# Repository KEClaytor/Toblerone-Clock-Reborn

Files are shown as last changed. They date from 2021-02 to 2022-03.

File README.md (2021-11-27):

# Toblerone-Clock-Reborn
Mk 2 of the Toblerone Clock

Digits:

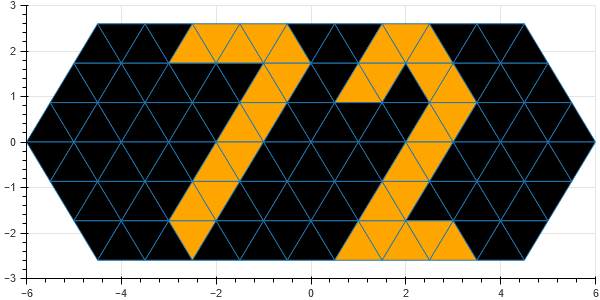
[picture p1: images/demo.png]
Numbers


Clock mode (hours are green, minutes orange, seconds blue):

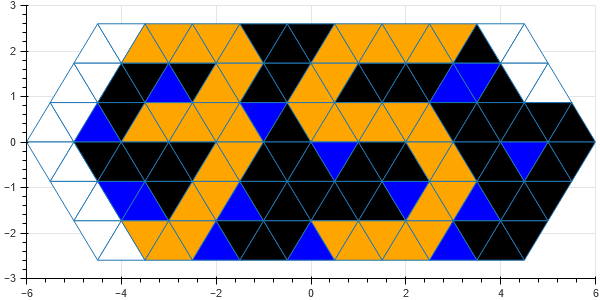
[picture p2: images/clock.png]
Clock mode


Pixel numbering scheme:

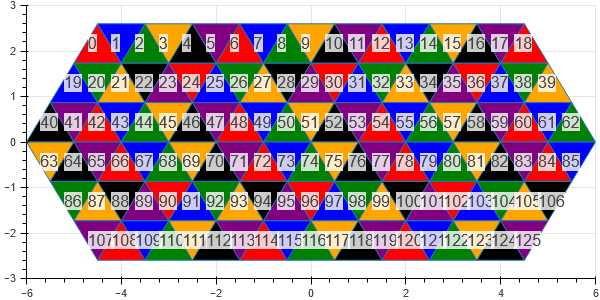
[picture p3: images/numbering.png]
Numbering


## Hardware

Wiring diagram (the pins tied together simulate how I created the nets on the protoboard).

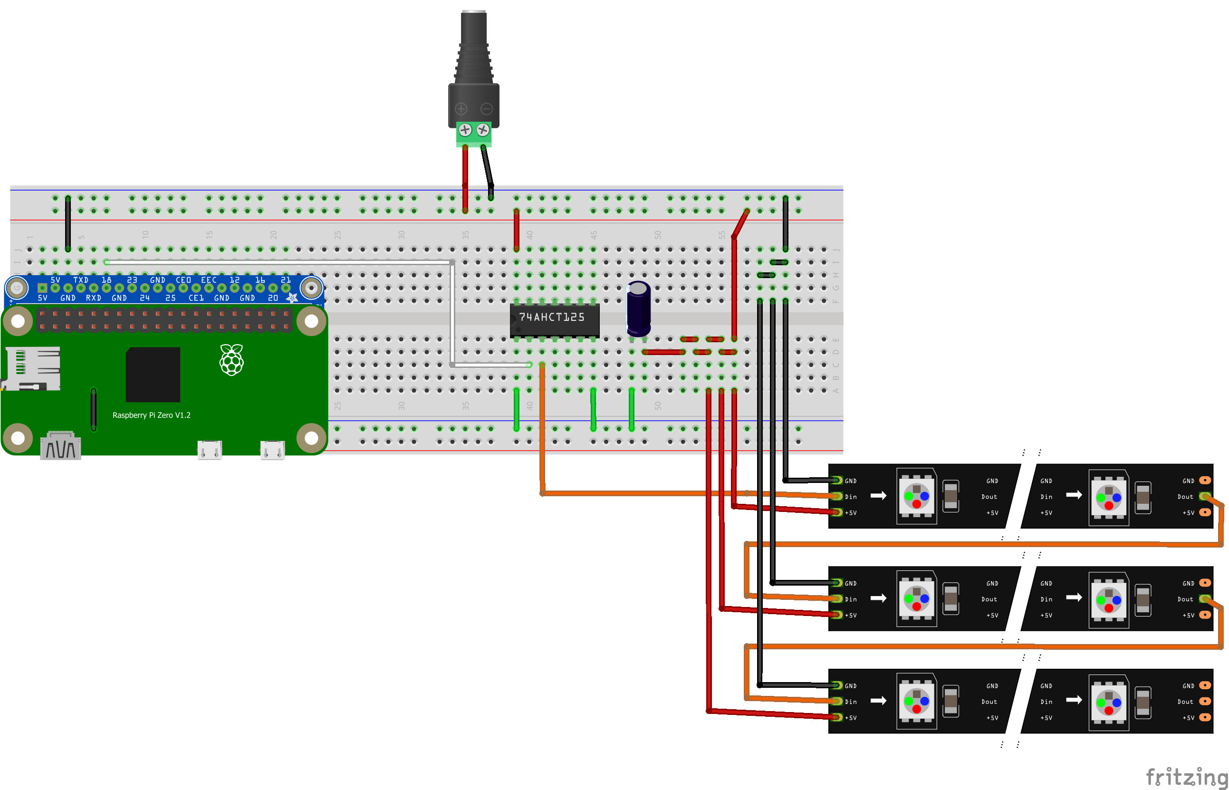
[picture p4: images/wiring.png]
Wiring diagram


## Installation

Standard system update and upgrade;
```
sudo apt update && sudo apt upgrade
```

For [`hostname.local` support](https://www.howtogeek.com/167190/how-and-why-to-assign-the-.local-domain-to-your-raspberry-pi/);
```
sudo apt-get install avahi-daemon
```

[Install Blinka from Adafruit](https://learn.adafruit.com/circuitpython-on-raspberrypi-linux?view=all);
```
sudo apt-get install python3-pip
sudo pip3 install --upgrade setuptools
cd ~
sudo pip3 install --upgrade adafruit-python-shell
wget https://raw.githubusercontent.com/adafruit/Raspberry-Pi-Installer-Scripts/master/raspi-blinka.py
sudo python3 raspi-blinka.py
```

[Install neopixel package](https://github.com/adafruit/Adafruit_CircuitPython_NeoPixel);
```
sudo pip3 install adafruit-circuitpython-neopixel
```

[Install docker and docker-compose](https://devdojo.com/bobbyiliev/how-to-install-docker-and-docker-compose-on-raspberry-pi);
```
curl -fsSL https://get.docker.com -o get-docker.sh
sudo sh get-docker.sh
sudo usermod -aG docker ${USER}
sudo su - ${USER}
docker version
docker run hello-world
sudo apt-get install libffi-dev libssl-dev
sudo pip3 install docker-compose
```

[Install requirements with poetry](https://python-poetry.org/docs/basic-usage/);
```
curl -fsSL https://raw.githubusercontent.com/python-poetry/poetry/master/get-poetry.py -o get-poetry.py
python3 get-poetry.py
poetry install
```

OR run with docker;
```
docker-compose up --build
```

## Interactive Designer

```
bokeh serve --show app.py
```

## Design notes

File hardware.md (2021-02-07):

# Hardware Notes

## Which pixels

Neopixels vs. dotstars?

What sort of spacing do we need (2 measurements on the toblerone spacing):
- 40 mm / 2 pixels = 20 mm / px
- 115 mm / 6 pixels = 19.16 mm / px

Spacing for a 30 px / m
- 1000 mm / 30 px = 33 mm / px - a little too much

[Best price on flexible connected pixels](https://www.adafruit.com/product/4560)
These look like the best, as I can center each one on the tube.

## Estimating power draw

[Powering guide](https://learn.adafruit.com/adafruit-neopixel-uberguide/powering-neopixels)

126 NeoPixels × 20 mA ÷ 1,000 = 2.52 Amps minimum
126 NeoPixels × 60 mA ÷ 1,000 = 7.56 Amps maximum

## External displays

[Display for Pi v1](https://www.adafruit.com/product/2097)
[Display for Pi 2+/0](https://www.adafruit.com/product/2441)

Do I even need a display?
I can just run the bokeh server over the local LAN and use an existing computer.

Do I want a display...?

## Wiring neopixels

[Pi <--> Neopixel wiring guide](https://learn.adafruit.com/neopixels-on-raspberry-pi/raspberry-pi-wiring)
Looks like I'll need either a [level shifter](https://www.adafruit.com/product/1787) (preferred) or a diode (see below).

> GPIO18 is the standard pin

> The diodes Adafruit sells only handle 1 Amp of continuous current so they're good for driving up to about 16 NeoPixels at full 100% bright white - and about 50 NeoPixels if they're all lit with various colors

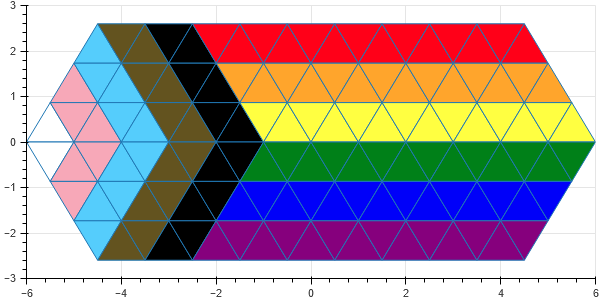
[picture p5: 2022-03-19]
images/pride.png

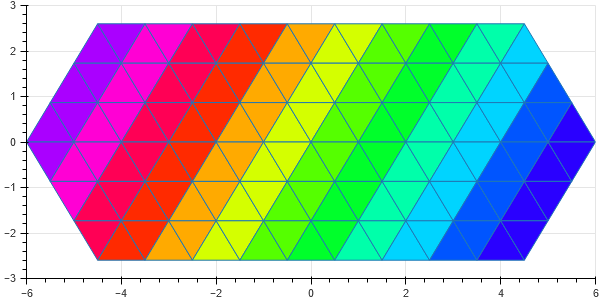
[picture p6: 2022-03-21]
images/rainbow.png

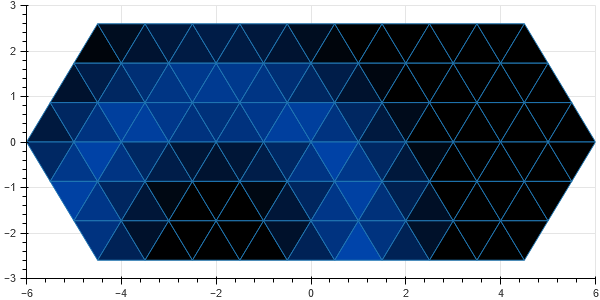
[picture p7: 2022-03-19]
images/raindrop.png

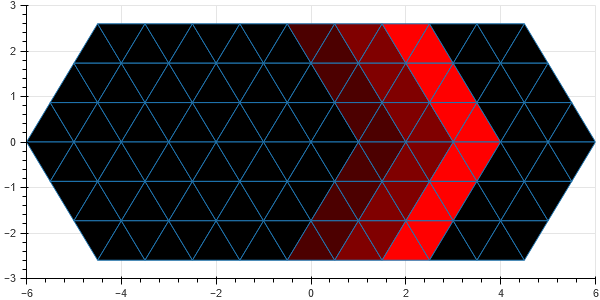
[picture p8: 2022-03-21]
images/chevrons.png

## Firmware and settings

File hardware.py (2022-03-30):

"""Hardware interface to the NeoPixels

Modified from; https://learn.adafruit.com/neopixels-on-raspberry-pi/python-usage
"""

import characters

try:
    import board
    import neopixel

    # NeoPixels must be connected to D10, D12, D18 or D21 to work.
    pixel_pin = board.D18
    num_pixels = 126

    pixels = neopixel.NeoPixel(pixel_pin, num_pixels, auto_write=False)

except ModuleNotFoundError:
    num_pixels = 126
    pixels = None


# Hardware pixel order
# Every other row is reversed
pixel_index_map = (
    characters.row_0
    + list(reversed(characters.row_1))
    + characters.row_2
    + list(reversed(characters.row_3))
    + characters.row_4
    + list(reversed(characters.row_5))
)


def hex_to_rgb(chex):
    """Convert color hex string to (r,g,b) tuple.
    """
    chex = chex.lstrip("#")
    return tuple(int(chex[ii : ii + 2], 16) for ii in (0, 2, 4))

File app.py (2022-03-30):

"""The main application

Use `bokeh serve --show` to run.
"""
import random
import datetime

import numpy as np

from bokeh.plotting import figure
from bokeh.models import ColumnDataSource
from bokeh.models import Panel, Tabs
from bokeh.models import TextInput, ColorPicker, Button, RadioButtonGroup, Select
from bokeh.io import curdoc
from bokeh.layouts import column
from bokeh.events import Tap

import core
import characters
import animations
import pride
import hardware

# Data
(x0, y0, xs, ys) = core.extended()
source = ColumnDataSource(
    data={"x0": x0, "y0": y0, "xs": xs, "ys": ys, "colors": ["#000000"] * len(x0)}
)
x0 = np.array(x0)
xs = np.array(xs)
y0 = np.array(y0)
ys = np.array(ys)
selected = np.zeros(x0.shape, dtype=bool)

# UI elements - Character designer
char_button = Button(label="Reset")
char_text = TextInput(value="[]", title="Selected Index:")

# UI elements - Color picker
color_button = Button(label="Reset")
color_text = TextInput(value="[]", title="Colors:")
color_picker = ColorPicker(title="Color")

# UI elements - Animation page
animation_radio = RadioButtonGroup(
    labels=["rainbow", "raindrops", "chevrons"], active=0
)

# UI elements - Pride page
pride_select = Select(title="Flag", options=list(pride.flags.keys()))

# Plot
p = figure(plot_width=600, plot_height=400, x_range=(-6, 6), y_range=(-4, 4),)
p.patches(xs="xs", ys="ys", fill_color="colors", source=source)


def write_ui(color_list):
    """Takes an RGB color list and writes it to the bokeh UI.
    """
    # Write to the ColumnDataSource to update the plot
    source.data["colors"] = color_list.tolist()


def write_hardware(color_list):
    """Takes an RGB color list and writes it to hardware.
    """
    if hardware.pixels:
        # Write each pixel according to the hardware index
        for ii in range(hardware.num_pixels):
            index = hardware.pixel_index_map[ii]
            color = hardware.hex_to_rgb(color_list[ii])
            hardware.pixels[index] = color
        # Write to the pixels
        hardware.pixels.show()


def write(colors):
    write_ui(colors)
    write_hardware(colors)


def reset(event):
    """Clear the display.
    """
    selected[:] = False
    colors = np.array([characters.COLOR_BLACK] * len(x0), dtype=object)
    write(colors)


def update_callback(event):
    """Update the colors based on an interaction.
    """
    colors = np.array(source.data["colors"], dtype=object)
    indx = np.argmin((x0 - event.x) ** 2 + (y0 - event.y) ** 2)
    if tabs.active == 0:
        # ==== Index Designer ====
        selected[indx] = not selected[indx]
        colors[~selected] = characters.COLOR_BLACK
        colors[selected] = characters.COLOR_ORANGE
        # Update the UI
        char_text.value = str(np.where(selected)[0].tolist())
    elif tabs.active == 1:
        # ==== Color Designer ====
        colors[indx] = color_picker.color
        # Update the UI
        color_text.value = str(colors.tolist())
    elif tabs.active == 2:
        # ==== Clock Mode ====
        # Update from clock()
        pass
    elif tabs.active == 4:
        # ==== Animations ====
        pass
    elif tabs.active == 5:
        # ==== Pride Flags ====
        pass
    write(colors)


rainbow_index = 0
raindrops = [(0, 0, 0), (-2, -2, 3), (2, 2, 5)]
chevron_index = 0
chevron_hue = random.randint(0, 360)


def update_periodic():
    """Update the display based on a periodic schedule.
    """
    colors = None
    if tabs.active == 0:
        # ==== Index Designer ====
        pass
    elif tabs.active == 1:
        # ==== Color Designer ====
        pass
    elif tabs.active == 2:
        # ==== Clock Mode ====
        dt = datetime.datetime.now()
        colors = animations.clock(dt.hour, dt.minute, dt.second)
    elif tabs.active == 3:
        # ==== Animations ====
        if animation_radio.active == 0:
            # ==== Rainbow ====
            global rainbow_index
            colors = animations.rainbow(rainbow_index)
            rainbow_index += 2
        elif animation_radio.active == 1:
            # ==== Raindrops ====
            global raindrops
            # Update radius
            raindrops = [(x, y, r + 0.5) for (x, y, r) in raindrops]
            # Cull large raindrops
            raindrops = [r for r in raindrops if r[2] < 10]
            # Add new raindrops
            if len(raindrops) < 3:
                x = random.uniform(-6, 6)
                y = random.uniform(-2.5, 2.5)
                r = 0
                raindrops.append((x, y, r))
            # Create the ripples
            colors = animations.ripple(x0, y0, 215, raindrops)
        elif animation_radio.active == 2:
            # ==== Chevrons ====
            # Chevrons move from -8 to +22
            # We map the index [0, 100] to [-8, 22]
            # We also only want even shift values
            global chevron_index
            global chevron_hue
            max_index = 30
            if chevron_index > max_index:
                chevron_hue = random.randint(0, 360)
                chevron_index = 0
            else:
                chevron_index += 1
            shift = int((chevron_index / max_index) * 30 - 8)
            if shift % 2 != 0:
                shift += 1
            colors = animations.chevron_right_fade(shift, chevron_hue)
    elif tabs.active == 4:
        # ==== Pride Flags ====
        pass
    if colors is not None:
        write(colors)


def update_attr(attr, old, new):
    """Update the display based on a selection.
    """
    colors = pride.flag(pride_select.value)
    write(colors)


# Register plot clicks
p.on_event(Tap, update_callback)
# Register resets
char_button.on_click(reset)
color_button.on_click(reset)
# Register a flag select
pride_select.on_change("value", update_attr)

# Add tab layouts
layout_char = column([char_button, char_text], width=800)
tab_char_designer = Panel(child=layout_char, title="Index Designer")

layout_color = column([color_button, color_text, color_picker], width=800)
tab_color_designer = Panel(child=layout_color, title="Color Designer")

tab_timer_demo = Panel(child=column([], width=800), title="Clock")

tab_animation = Panel(child=column([animation_radio], width=800), title="Animations")

tab_pride = Panel(child=column([pride_select], width=800), title="Pride",)

# Add all tabs
tabs = Tabs(
    tabs=[
        tab_char_designer,
        tab_color_designer,
        tab_timer_demo,
        tab_animation,
        tab_pride,
    ],
    width=800,
)

layout = column([tabs, p], width=800)

# Add periodic (eg; time-based) callbacks
curdoc().add_periodic_callback(update_periodic, 200)
curdoc().add_root(layout)

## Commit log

2021-02-07 Adding in character set for numbers, reset button for index designer.
2021-11-27 Initial take a dockerfile, adding wiring diagram.
    [Wiring.fzz]
2022-03-19 Switching bokeh color, and adding short docstrings.
    [app.py, characters.py, core.py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]
2022-03-19 Missing update to characters.py
    [characters.py]
2022-03-19 Refactored for better clarity, resolved bokeh RGB/HSV issue.
    [animations.py, app.py, characters.py]
2022-03-20 Fix to hardware implementation.
    [hardware.py]
2022-03-21 Bugfixes / tweaks to clock
    [animations.py, app.py, characters.py]
2022-03-30 Bugfix to color picker.
    [app.py]
